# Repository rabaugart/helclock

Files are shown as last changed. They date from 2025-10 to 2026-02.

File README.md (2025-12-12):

# helclock

## Text

10 Zeilen, 11 Spalten

    ESKISTAFÜNF
    ZEHNZWANZIG
    DREIVIERTEL
    VORFUNKNACH
    HALBAELFÜNF
    EINSXAMZWEI
    DREIPMJVIER
    SECHSNLACHT
    SIEBENZWÖLF
    ZEHNEUNKUHR

Anpassungen

    ESBISTAFÜNF
      -
    ZEHNZWANZIG
    DREIVIERTEL
    VORBESONACH
       ----
    HALBAELFÜNF
    EINSDOMZWEI
        --
    DREIHELVIER
        ---
    SECHSRAACHT
         --
    SIEBENZWÖLF
    ZEHNEUNFUHR
           -

## Segmente



## LED-Varianten

- Pollin-[Sortiment](https://www.pollin.de/p/sort-led-neopixel-programmierbar-800567) programmierbar, mit SK6812 und WS2812B, 40 Stck 2,95€.
- Digikey-[Kategorie](https://www.digikey.de/de/products/filter/leds-adressierbar-spezialanwendungen/126) für programmierbare LEDs.
- Adafruit-Neopixel 5050 bei [berrybase](https://www.berrybase.de/adafruit-neopixel-5050-rgb-led-mit-integriertem-treiber-10-stueck)
  oder [Mouser](https://www.mouser.de/ProductDetail/Adafruit/3094?qs=SV%252B0z0o3NTt%2F2YK7E3w5Rg%3D%3D) 100 Stck, 25,76€.
- THT-Leds mit WS2812 bei [Berrybase](https://www.berrybase.de/adressierbare-ws2812-rgb-led-pth-5mm-diffus-5er-pack),
  von [Sparkfun](https://learn.sparkfun.com/tutorials/ws2812-breakout-hookup-guide#addressable-through-hole-led)
- Neopixel [Nano](https://www.adafruit.com/product/4684) castellated, 10 Stück, 4,24€ bei [Antratek](https://www.antratek.de/neopixel-nano-2020-rgb-leds-10-pack-ws2812b)
- Berrybase [Streifen](https://www.berrybase.de/digitaler-led-rgb-neopixel-stripe-ip65-vergossen-30-leds-schwarz-50cm-mit-kabelanschluss)
  mit 30 LEDs auf 50cm.
- LED-[Matrix](https://eckstein-shop.de/WaveShare-RGB-Full-Color-LED-Matrix-Panel-64x64-Pixels-3mm-Pitch-Adjustable-Brightness) bei Eckstein
- Adressierbare [LED-Streifen](https://www.pololu.com/product/3086) bei Pololu
- Adressierbare [LED-Streifen](https://www.tme.eu/de/details/n013060ca3sa1/lichtquellen-led-bander/ipixel-led/) bei TME.
- Einzelne, adressierbare, programmierbare [LED](https://eu.robotshop.com/products/5mm-adressable-rgb-led-5pk) THT bei RobotShop
- Einzelne, programmierbare LEDs auf Breakout bei [Watterott](https://shop.watterott.com/WS2812B-Breakout-Intelligent-RGB-LED-5-Stk) mit WS2812B-Controller.
THT-LEDs

### Adressierbare LEDs, THT



Infos bei [Sparkfun](https://learn.sparkfun.com/tutorials/ws2812-breakout-hookup-guide#addressable-through-hole-led)



NeoPixel-[Library](https://github.com/adafruit/Adafruit_NeoPixel) von Adafruit

### Berrybase-Streifen



Neopixel 5050



### Neopixel Nano 2020, castelleted

Verwendet WS2812B, könnte evtl Worldsemi [2812-2020](http://world-semi.com/ws2812-family/) entsprechen.

Listing bei [Mouser](https://www.mouser.de/ProductDetail/Adafruit/4684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).





## Analoge LED-Treiber

Kategorie bei [Mouser](https://www.mouser.de/c/semiconductors/driver-ics/led-lighting-driver-ics/)

Als Schieberegister beispielsweise von [TI](https://www.mouser.de/ProductDetail/Texas-Instruments/TLC5916INE4?qs=vPP9GyyTAo06VIPRtWrixw%3D%3D)

## Controller

- [ESP32-C6](https://docs.espressif.com/projects/esp-dev-kits/en/latest/esp32c6/esp32-c6-devkitm-1/user_guide.html)

## Distributoren

- [Antratek](https://www.antratek.de/)

## Alternative Projekte

- RPi-[Wordclock](https://github.com/bk1285/rpi_wordclock)

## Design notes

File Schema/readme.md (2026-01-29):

# Pi-Board

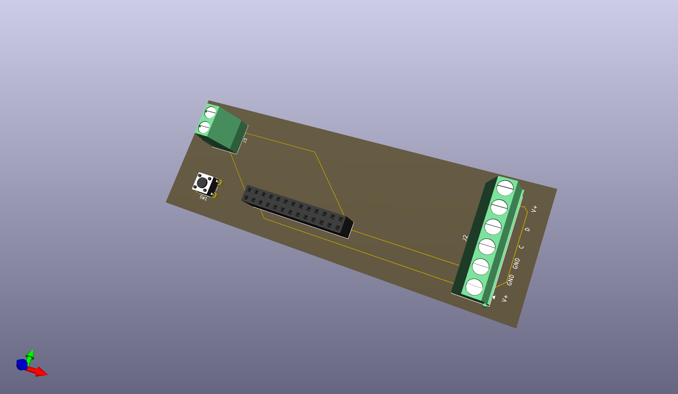
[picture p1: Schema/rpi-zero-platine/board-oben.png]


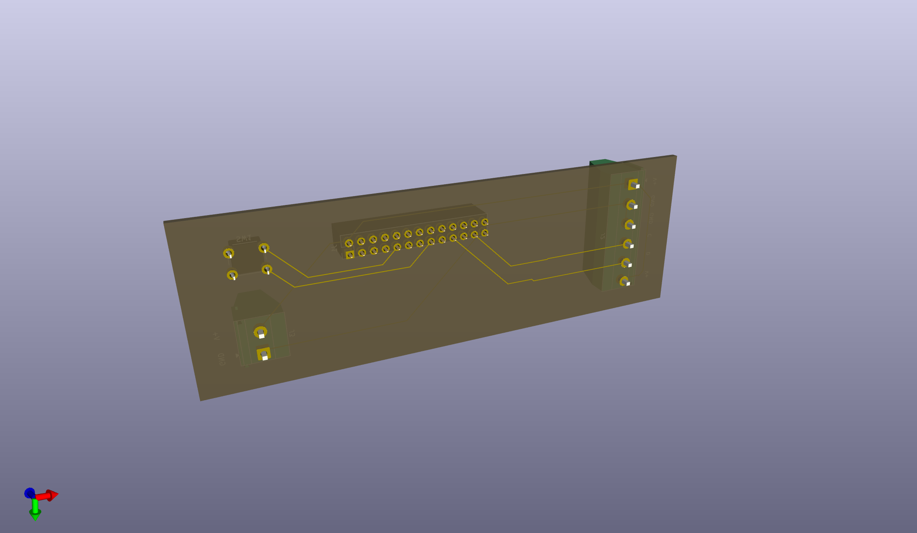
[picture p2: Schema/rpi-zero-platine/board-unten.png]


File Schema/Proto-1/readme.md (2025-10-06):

# Schema Development Board













Ressourcen:

- [Kicad](https://github.com/espressif/kicad-libraries) Library von Espressif

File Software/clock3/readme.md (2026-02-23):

## Starten

Starten der Uhr mit dem `quart`-Server

    python -m c3.server [service|service_min|test]

Kontext `service|service_min` mit|ohne Minutenanzeige
Default ist `service` (`controler.py`).

Starten der `curses`-Clock

    python -m c3

Ausführen der Unittests

    python -m unittest c3

## Weitere Infos

Farbausgabe auf dem Terminal

* [Wiki](https://en.wikipedia.org/wiki/ANSI_escape_code)
* [ansi](https://github.com/fidian/ansi)-Skript
* ansi-[Farben](https://gist.github.com/JBlond/2fea43a3049b38287e5e9cefc87b2124)

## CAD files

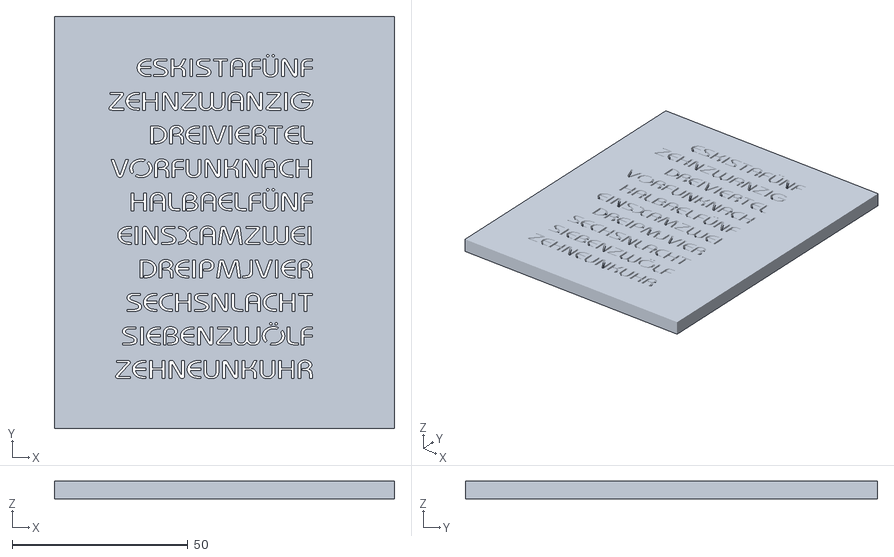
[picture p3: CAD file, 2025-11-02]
Frontplatte/bauhaus-Part.stl
96.7 x 117.1 x 5.00

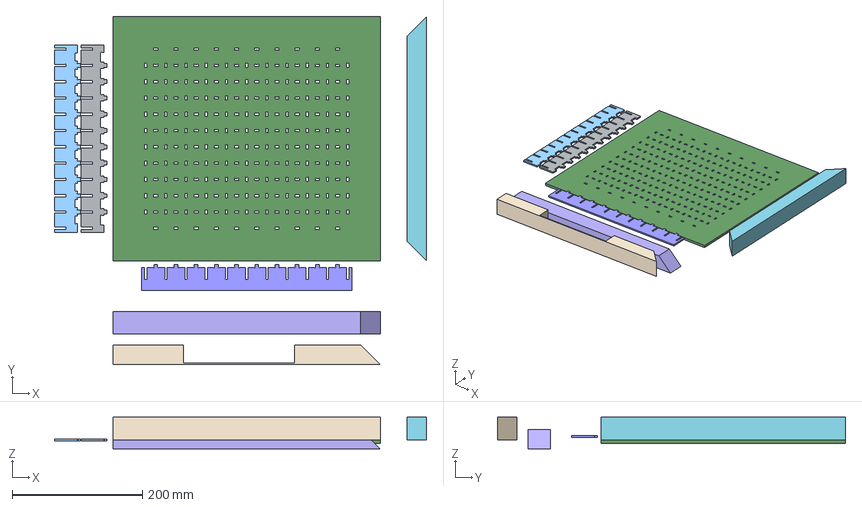
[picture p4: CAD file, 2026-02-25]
Mechanik/Export/TeileExport.step
571.0 x 534.0 x 48.5 mm
QuerBody
PomLinks
Querwand_aussen
PomOben
PomRechts

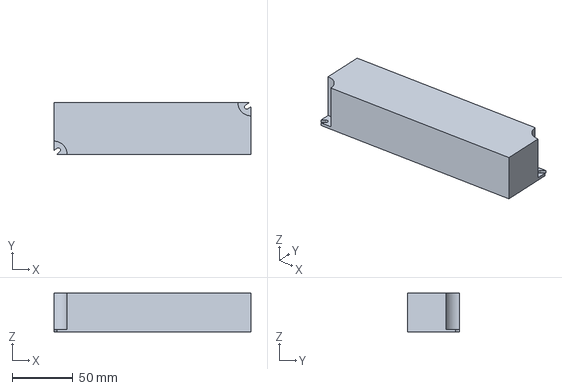
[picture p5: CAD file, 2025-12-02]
Mechanik/meanwell-netzteil.FCStd
162.5 x 42.5 x 32.0 mm

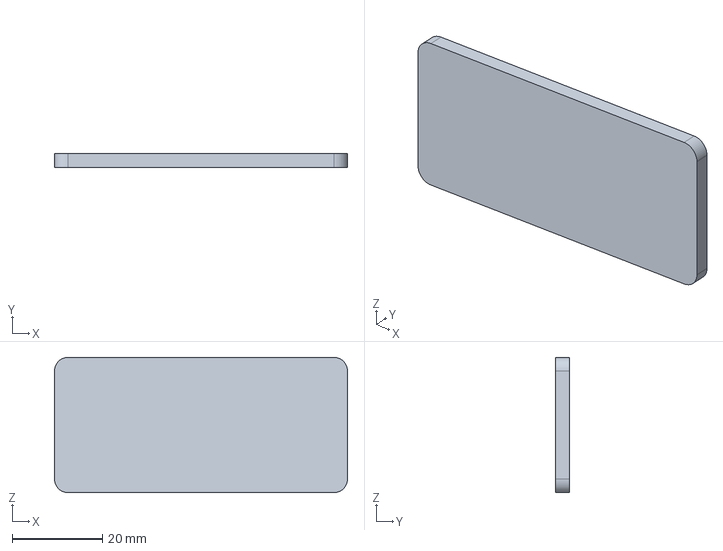
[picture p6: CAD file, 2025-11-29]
Mechanik/Pi-Mockup.FCStd
65.0 x 3.00 x 30.0 mm

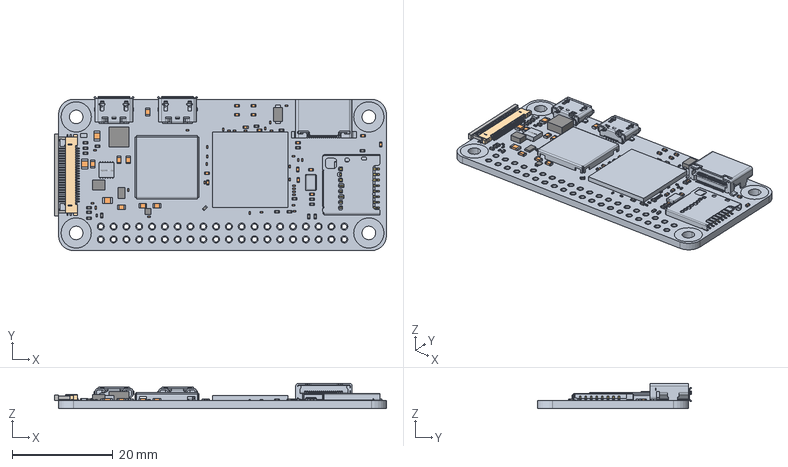
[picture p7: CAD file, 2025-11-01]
Mechanik/Raspberry Pi Zero 2 W with Textures.stp
65.8 x 30.6 x 5.05 mm

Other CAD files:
Mechanik/Helclock.FCStd
Frontplatte/bauhaus.FCStd
Mechanik/Export/TeileExport.stl

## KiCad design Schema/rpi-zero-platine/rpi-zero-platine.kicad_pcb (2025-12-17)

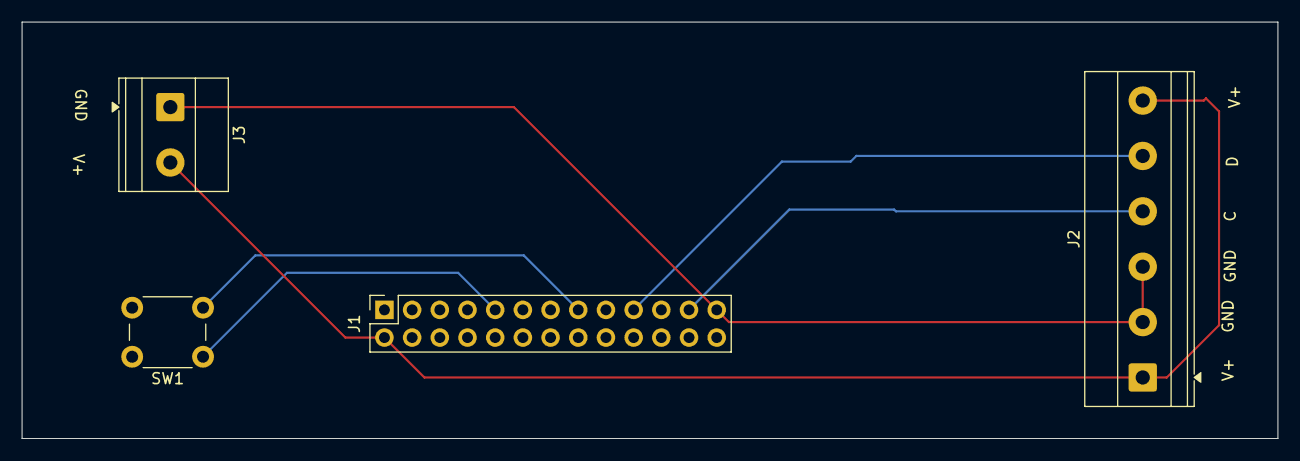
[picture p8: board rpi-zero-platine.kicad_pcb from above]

Board: 2 copper layers, 115.2 x 38.2 mm, 4 parts (0 on the bottom side), 6 nets.

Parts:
J1: GPIO; PinSocket_2x13_P2.54mm_Vertical
J2: LED Out A; TerminalBlock_Phoenix_MKDS-1,5-6-5.08_1x06_P5.08mm_Horizont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
J3: LED Out B; TerminalBlock_Phoenix_MKDS-1,5-2-5.08_1x02_P5.08mm_Horizont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
SW1: SW_DIP_x02; SW_PUSH_6mm_H4.3mm

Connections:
+5V: J1.2 (VCC), J2.1, J2.6, J3.2 (LEDB+)
/Clock: J1.23 (SPI0.SCLK), J2.4
/Data: J1.19 (SPI0.MOSI), J2.5
GND: J1.25 (GND), J2.2, J2.3, J3.1 (LEDB-)
unnamed: J1.9, SW1.1
unnamed: J1.15, SW1.2

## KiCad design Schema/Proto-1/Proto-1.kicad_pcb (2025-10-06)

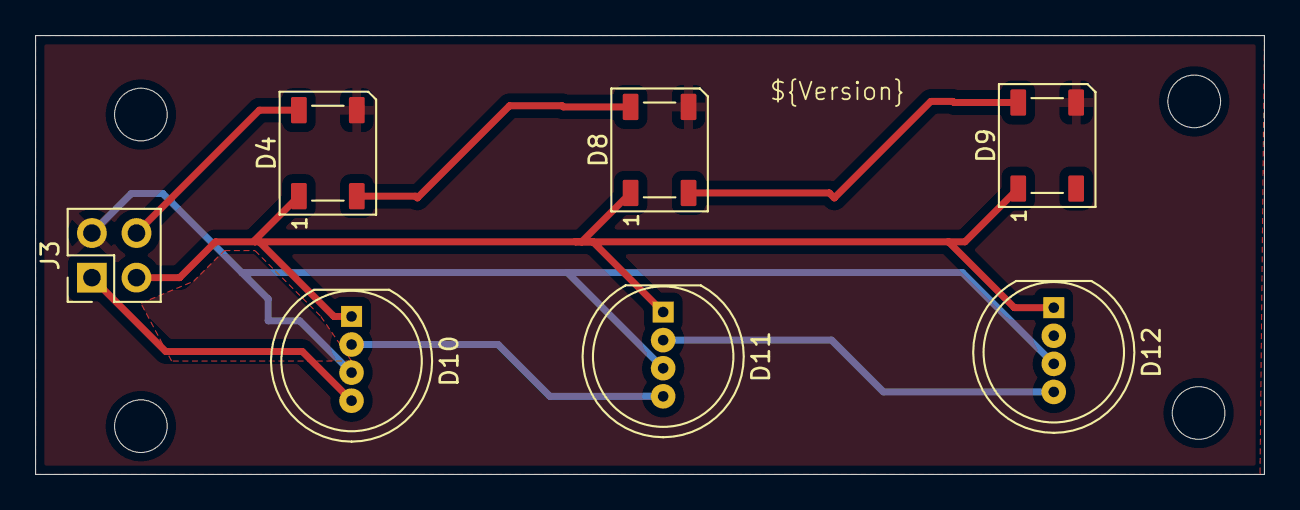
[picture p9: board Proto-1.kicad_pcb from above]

Board: 2 copper layers, 70.0 x 25.0 mm, 7 parts (0 on the bottom side), 8 nets.

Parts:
D4, D8, D9: LED-Brightek; LED-SMD-Brightek-N0M50S18IC_5.0x5.0mm_P3.2mm
D10, D11, D12: LED_THT-OSTWMN8132A; LED_D8.0mm-4
J3: Conn_02x02_Counter_Clockwise; PinHeader_2x02_P2.54mm_Vertical

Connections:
+5V: D4.1 (VDD), D8.1 (VDD), D9.1 (VDD), D10.1 (VCC), D11.1 (VCC), D12.1 (VCC), J3.3
GND: D4.3 (VSS), D8.3 (VSS), D9.3 (VSS), D10.3 (VSS), D11.3 (VSS), D12.3 (VSS), J3.2
unnamed: D4.4 (DIN), J3.4
unnamed: D4.2 (DOUT), D8.4 (DIN)
unnamed: D8.2 (DOUT), D9.4 (DIN)
unnamed: D10.4 (DIN), J3.1
unnamed: D10.2 (DOUT), D11.4 (DIN)
unnamed: D11.2 (DOUT), D12.4 (DIN)

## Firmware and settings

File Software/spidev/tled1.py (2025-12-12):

#!/usr/bin/env python

import spidev, time

spi = spidev.SpiDev()

spi.open(0,0)

spi.max_speed_hz = 2000000
#spi.mode = 1
#spi.bits_per_word = 8
#spi.lsbfirst = False

länge = 11

class Color:
    def __init__(self,r,g,b):
        self.b = bytearray([r,g,b])

    def sendn(self,n=länge,sleep=1.0):
        spi.writebytes(self.b*n)
        if sleep:
            time.sleep(sleep)

    def send(self,sleep=None):
        print(f"Sending {self.b}")
        spi.writebytes(self.b)
        #spi.xfer(self.b,1000000, 1)
        if sleep:
            time.sleep(sleep)

blau = Color(0,0,0xFF)
rot = Color(0xFF,0x00,0x00)
grün = Color(0x00,0xFF,0X00)
schwarz = Color(0,0,0)
weiss = Color(0xFF,0xFF,0xFF)
gelb = Color(0xFF,0xFF,0x00)

while True:
    blau.sendn()
    rot.sendn()
    grün.sendn()
    weiss.sendn()
    gelb.sendn()
    spi.writebytes((blau.b+rot.b+grün.b)*4)
    time.sleep(1)
    spi.writebytes(schwarz.b*11)
    time.sleep(1)

spi.close()

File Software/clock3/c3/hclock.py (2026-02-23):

import math, re, functools, datetime, itertools
from datetime import time
from enum import Enum

import unittest

from .color import colors_bytes, SCHWARZ, ROT
from .xtra import XW

from .worte import W, MIW, zeige_minuten, aktiviere_minutenanzeige

try:
    from .spi import Spi
except:
    from .tspi import Spi

TEXT = [
# 01234567890
("ESBISTAFÜNF", [ W.ES, W.IST, W.FÜNF_A, XW.B ]), # 0
("ZEHNZWANZIG", [ W.ZEHN_A, W.ZWANZIG ]), # 1
("DREIVIERTEL", [ W.DREI_A, W.VIERTEL ]), # 2
("VORBESONACH", [ W.VOR, W.NACH, XW.BE, XW.SO ]), # 3
("HALBAELFÜNF", [ W.HALB, W.ELF, W.FÜNF_B ]), # 4
("EINSDOMZWEI", [ W.EIN, W.EINS, W.ZWEI, XW.DOM ]), # 5
("DREIHELVIER", [ W.DREI_B, W.VIER, XW.HEL ]), # 6
("SECHSRAACHT", [ W.SECHS, W.ACHT, XW.RA ]), # 7
("SIEBENZWÖLF", [ W.SIEBEN, W.ZWÖLF ]), # 8
("ZEHNEUNFUHR", [ W.ZEHN_B, W.NEUN, W.UHR, XW.F ]), # 9
]

def koordinaten_buchstabe(r,c):
    "Buchstabe an der Position r,c"
    if r==NROWS:
        # Die Minutenanzeige
        return 'X'
    return TEXT[r][0][c]

STAMM_RE = re.compile("^([^_]+).*$",re.U)

def wort_stamm(w):
    "Entferne _A, _B"
    m = STAMM_RE.match(w.name)
    assert(m)
    return m.groups()[0]

def wort_koordinaten(w):
    if w in MIW:
        # Alle Minuten-LEDs bis zum Wert
        return [(NROWS,i) for i in range(w.value)]
    l = [ (i,t) for (i,(t,l)) in enumerate(TEXT) if w in l ]
    assert(len(l)==1)
    (row,t) = l[0]
    ws = wort_stamm(w)
    col = t.find(ws)
    assert(col>=0)
    return [(row,col+i) for i in range(len(ws))]

NROWS = 10
NCOLS = 11
NMINUTE = len(MIW)
MAX_INDEX = NROWS*NCOLS+NMINUTE

#
# (0,0) -> 10
# (1,0) ->  9
# (10,0) -> 0
# (0,1) -> 11
#
# Indexe:
# Col   0   1   2 ..  9   10
#       ⬆  ⬇  ⬆     ⬇   ⬆
# r0  109  90  89 .. 10    9
# r1  108  91  88 .. 11    8
# r.   ..  ..  .. .. ..   ..
# r8  101  98  81 .. 18    1
# r9  100  99  80    19    0

# Die Reihe mit den Minuten
# r10 110 111 112 113

def koordinaten_index(r,c):
    "Abbildung r,c -> i"
    assert(r>=0 and r<(NROWS+1) and c>=0 and (c < NCOLS if r<=NROWS else c<len(MIW)))
    if r == 10:
        # Die Minutenreihe zählt einfach hoch
        return NROWS*NCOLS+c
    top = (NROWS*NCOLS-1) - NROWS*c # Oberste Reihe
    return top-r if c % 2 == 0 else top-(NROWS-1)+r

def index_koordinaten(i):
    "Abbildung i -> r,c"
    assert(i>=0 and i<MAX_INDEX)
    if i>=NROWS*NCOLS:
        return NROWS,i-NROWS*NCOLS
    c = NROWS-math.floor(i / NROWS)
    top = NROWS*NCOLS-1 - NROWS*c
    r = top-i if c%2 == 0 else i-top+NROWS-1
    return r,c

def index_range():
    return range(MAX_INDEX)

def koordinaten_range():
    return itertools.chain(
        itertools.product( range(NROWS), range(NCOLS)),
        [(NROWS,i) for i in range(len(MIW))])

# Die im Satz zu nutzende Stunde
S = Enum('Stunde',[
    "DIESE",    # Rendere diese Stunde
    "NÄCHSTE",  # Rendere diese Stunde
    "VOLLE"     # Rendere diese Stunden zur vollen Stunde (EIN <-> EINS)
])

# Satzfragmente in Abhängigkeit von der Minute
# "ES IST"  und "UHR" fehlen und müssen immer dazu gesetzt werden
SATZ_INDEX = [
    [S.VOLLE, W.UHR], # Minute 0..5
    [W.FÜNF_A, W.NACH, S.DIESE], # Minute 5..10
    [W.ZEHN_A, W.NACH, S.DIESE], # ...
    [W.VIERTEL, W.NACH, S.DIESE],
    [W.ZWANZIG, W.NACH, S.DIESE],
    [W.FÜNF_A, W.VOR, W.HALB, S.NÄCHSTE],
    [W.HALB, S.NÄCHSTE],
    [W.FÜNF_A, W.NACH, W.HALB, S.NÄCHSTE],
    [W.ZWANZIG, W.VOR, S.NÄCHSTE],
    [W.VIERTEL, W.VOR, S.NÄCHSTE],
    [W.ZEHN_A, W.VOR, S.NÄCHSTE],
    [W.FÜNF_A, W.VOR, S.NÄCHSTE],
]

def satz_index(ti):
    "Finde den Index für das Satzfragment zur Uhrzeit anhand der Minute"
    return math.floor(ti.minute*len(SATZ_INDEX)/60.0)

def satz_vorlage(ti):
    "Satzvorlage mit Stundenplatzhalter zur Uhrzeit"
    return [W.ES,W.IST] + SATZ_INDEX[satz_index(ti)]

# Stundenworte zur Stunde
STUNDEN = [W.ZWÖLF,W.EINS,W.ZWEI,W.DREI_B,W.VIER,W.FÜNF_B,W.SECHS,W.SIEBEN,W.ACHT,W.NEUN,W.ZEHN_B,W.ELF]

def stundenwort(st):
    "Stundenwort zur Stunde"
    return STUNDEN[st % len(STUNDEN)]

def ersetze_stunde(wort,ti):
    "Ersetze S.DIESE/S.NÄCHSTE/S.VOLLE durch Stundenwort"
    if wort == S.DIESE:
        return stundenwort(ti.hour)
    if wort == S.NÄCHSTE:
        return stundenwort(ti.hour+1)
    if wort == S.VOLLE:
        return W.EIN if ti.hour in (1,13) else stundenwort(ti.hour)
    return wort

def wort_indexe(w):
    "Tupel mit allen Indexen für ein Wort: (w,[i0,i1...])"
    return (w,[koordinaten_index(*k) for k in wort_koordinaten(w)])

def default_zeit():
    return datetime.datetime.now().time()

def minuten_satz(ti):
    "Satz für die Minutenanzeige, leere Liste bei ti.minute%5 == 0"
    if zeige_minuten():
        return [ i for i in MIW if (ti.minute%5) == i.value]
    return []

def zeit_satz(ti=None,mit_minuten=False):
    "Vollständiger Satz zur Uhrzeit als Liste von Worten ohne/mit Minuten"
    t = ti if ti else default_zeit()
    zs = [ersetze_stunde(w,t) for w in satz_vorlage(t)]
    return zs + minuten_satz(t) if mit_minuten else zs

def zeit_satz_indexe(ti=None,mit_minuten=False):
    "Alle Indexe des Satzes zur Zeit ti"
    l = sum( (wort_indexe(i)[1] for i in zeit_satz(ti,mit_minuten)), [] )
    l.sort()
    return l

def index_buchstaben_pos(il=None):
    "Liste mit (b,i,r,c) für Indexe"
    l = il if il else index_range()
    t = []
    for i in l:
        r,c = index_koordinaten(i)
        t.append((koordinaten_buchstabe(r,c),i,r,c))
    return t

def index_test_string(il=None):
    "Indexliste gerendert als String für die Terminal-Ausgabe"
    t = index_buchstaben_pos(il)
    return "\n".join( "".join(b for (b,i,r,c) in t if r==ar) for ar in range(NROWS) )

def zeit_ascii_string(ti=None):
    "Uhrzeit gerendert als String für die Terminal-Ausgabe"
    return index_test_string(zeit_satz_indexe(ti))

def zeit_spi_generator(ti=None):
    "Einfacher Generator nur für Zeitsätze mit Vorder- und Hintergrundfarbe"
    bg_color = SCHWARZ
    fg_color = ROT
    while True:
        t = ti if ti else default_zeit()
        s = zeit_satz_indexe(t)
        yield list( (fg_color if i in s else bg_color) for i in index_range() )
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

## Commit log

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2025-09-11 Beginne Prototyp 1
    [Spice.kicad_pcb, Spice.kicad_sch]
2025-09-11 Teste Exportmöglichkeiten
    [Spice.kicad_pcb, Spice.stl]
2025-09-11 Ändere Konnektor, korrigiere Pfadbreiten
    [Spice.kicad_pcb, Spice.kicad_sch, Spice.stl]
2025-09-11 Erzeuge Output für p1-0.2
    [Spice.stl]
2025-09-11 Räume Schema auf
    [Spice.kicad_pcb, Spice.kicad_sch, Spice.stl]
2025-09-11 Ergänze eine Zone ohne Net am Konnektor
    [Spice.kicad_pcb]
2025-09-12 Verkleinere die Fläche, füge Bohrungen ein
    [Spice.kicad_pcb, Spice.kicad_sch]
2025-09-12 Benenne um Spice -> Proto-1
    [Spice.kicad_pcb, Spice.kicad_sch]
2025-09-12 Benenne Files um
    [Proto-1.kicad_pcb, Proto-1.kicad_sch]
2025-09-12 Erstelle Schema für B
    [Proto-1.kicad_pcb, Proto-1.kicad_sch, Proto-1b.kicad_sch]
2025-09-13 Beginne Devboard
    [Proto-1.kicad_pcb, Proto-1.kicad_sch, Proto-1b.kicad_sch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]
2025-09-13 Erstelle PCB für Devboard, ersetzte Proto-1-Board
    [Proto-1.kicad_pcb, Proto-1b.kicad_sch, devboard-esp32c6.kicad_sch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]
2025-09-13 Bereite DB1-0.4 vor
    [Proto-1.kicad_pcb, devboard-esp32c6.kicad_sch]
2025-09-13 Bereite Proto-1-0.5a vor, setze Sheet-Propery "exclude from board"
    [Proto-1.kicad_pcb, Proto-1.kicad_sch, Proto-1b.kicad_sch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]
2025-10-29 Erste Skizze mit Querwand
    [Skizze.FCStd]
2025-10-29 Mache Anzahl parametrisch
    [Skizze.FCStd]
2025-10-30 Füge Wände ein
    [Skizze.FCStd]
2025-10-30 Füge Nuten mit Spiel in die Wände ein
    [Skizze.FCStd]
2025-10-30 Verkleinere Wanddicke und Wandspiel
    [Skizze.FCStd]
2025-10-30 Füge Grundplatte hinzu
    [Skizze.FCStd]
2025-10-30 Füge Front hinzu
    [Skizze.FCStd]
2025-11-01 Benenne um, füge Font hinzu
    [Helclock.FCStd]
2025-11-01 Füge Step-Datei für Pi Zero 2 W hinzu
    [Raspberry Pi Zero 2 W with Textures.stp]
2025-11-01 Füge Mockup für Pi Zero hinzu
    [Helclock.FCStd]
2025-11-01 Füge Zungen in Grundplatte hinzu
    [Helclock.FCStd]
2025-11-02 Füge Gruppen in den Baum ein
    [Helclock.FCStd]
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2025-11-02 Füge vertikales Spiel in den Wandgehrungen hinzu
    [Helclock.FCStd]
2025-11-02 Vollständige Frontplatte mit Font
    [bauhaus-Part.stl, bauhaus.FCStd]
2025-11-04 Füge Fräsecken und Überstande in Quer- und Längswand ein
    [Helclock.FCStd]
2025-11-04 Erzeuge Link für Grundplatte
    [Helclock.FCStd]
2025-11-04 Füge Fräsecken in Grundplatte ein
    [Helclock.FCStd]
2025-11-04 Vergrößere Segmentlänge von 30 auf 31mm, vergrößere Wandhöhe von 25 auf 30mm
    [Helclock.FCStd]
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2025-11-05 Verschiebe den Raspi, fixe die fehlende Multitransform in der Grundplatte
    [Helclock.FCStd]
2025-11-10 Füge Bemaßung für Raster hinzu
    [Helclock.FCStd]
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2025-11-15 Vergrößere die Schlitze in der Grundplatte
    [Helclock.FCStd]
2025-11-15 Korrigiere Nasenlaenge, aktualisiere Zeichnung
    [Helclock.FCStd]
2025-11-16 Verschiebe die Bemassung der Längswand
    [Helclock.FCStd]
2025-11-16 Füge Fräsradien an der Nase hinzu
    [Helclock.FCStd]
2025-11-16 Lösche kaputtes Mass in der Zeichnung an der Längswand
    [Helclock.FCStd]
2025-11-16 Ändere Sichtbarkeit auf Montage
    [Helclock.FCStd]
2025-11-16 Füge Fräsradien an den Zapfen der Querwand hinzu
    [Helclock.FCStd]
2025-11-16 Exportiere STL und STEP, verschiebe Zeichnung, entferne alte Exports
    [Helclock-mit-Front.stl, Helclock-ohne-Front.stl, Helclock.FCStd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]
2025-11-29 Füge Meanwell Netzteil hinzu
    [meanwell-netzteil.FCStd]
2025-11-29 Füge Pi Mockup hinzu
    [Pi-Mockup.FCStd]
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2025-11-30 Vergrößere Massstab für LED in TechDraw
    [Helclock.FCStd]
2025-11-30 Korrigiere Massstabsangaben in TechDraw
    [Helclock.FCStd]
2025-11-30 Vergrößere Reihenabstand, verschiebe Raspi, exportiere neu
    [Helclock.FCStd, Teile.step, Teile.stl]
2025-11-30 Füge Fräsecken an den Nasen der Querwand ein
    [Helclock.FCStd]
2025-11-30 Füge Fräsecken an den Zungen der Längswand ein
    [Helclock.FCStd]
2025-11-30 Grundplattendicke -> 5mm, Wandhöhe -> 35mm, Frontplattenüberstand -> 50mm, Grundplattenüberstand -> 45mm
    [Helclock.FCStd]
2025-11-30 Füge Überstände als benannte Constraints in Basisabmessungen ein
    [Helclock.FCStd]
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2025-11-30 Füge weitere Daten in die Zeichnung ein
    [Helclock.FCStd]
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2025-12-01 Vergrößere auf 10x11, Überhänge += 5mm, verlinke Netzteil
    [Helclock.FCStd, TeileExport.step, meanwell-netzteil.FCStd]
2025-12-01 Verbessere die Zeichnung, insbesondere die Bemaßung
    [Helclock.FCStd]
2025-12-01 Setze Datum in der Zeichnung auf auto
    [Helclock.FCStd]
2025-12-02 Verbessere Bemaßung an Längs- und Querwand
    [Helclock.FCStd]
2025-12-02 Verringere die Banddicke auf 2,2 mm
    [Helclock.FCStd]
2025-12-02 Setze die Banddicke zurück und Schlitzhöhe auf Banddicke + 0,2 mm (statt 1mm)
    [Helclock.FCStd, TeileExport.step]
2025-12-02 Füge Querwand aussen hinzu
    [Helclock.FCStd, TeileExport.step]
2025-12-02 Exporte Teile als Mesh
    [TeileExport.stl]
2025-12-04 Setze Tagfeld in Zeichnung auf m-0.5
    [Helclock.FCStd]
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2025-12-13 Fix q-Bug in clcurses
    [clcurses.py]
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2025-12-16 Skizziere Platine für rpi zero
    [rpi-zero-platine.kicad_pcb, rpi-zero-platine.kicad_sch]
2025-12-16 Ändere Footprint der Schraubklemmen auf Phoenix mit 3D-Model
    [rpi-zero-platine.kicad_pcb]
2025-12-16 Ändere Footprint des Switches
    [rpi-zero-platine.kicad_pcb]
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2025-12-29 Entferne flask, fixe Test
    [test.py]
2026-01-01 Korrigiere Fehler bei Verwendung der Farbmap in ColWortGenerator
    [color.py, generator.py]
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2026-02-22 Korrigiere Fehler in hclock.index_range
    [generator.py, hclock.py, test.py]
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2026-02-25 3 POM-Teile, rechts mit Ausschnitt
    [Helclock.FCStd]
2026-02-25 Aussparung PomOben für Kabel
    [Helclock.FCStd, TeileExport.step, TeileExport.stl]
